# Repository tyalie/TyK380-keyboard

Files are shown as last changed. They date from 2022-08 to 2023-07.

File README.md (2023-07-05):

# TyK380 - A Logitech K380 based custom membrane keyboard

This project uses Logitech K380 keyboard and fully replaces its internal logic,
equipping it with cool features like the ZMK keyboard firmware, USB and an integrated
Li-Ion battery.

## The "_Whyyy_ thoo?"

This project was born out of the need for a very robust but lightweight keyboard and
my custom key layout needs. I wanted a keyboard where one doesn't need an extra
casing when it is squeezed between your laptop and books inside an already struggling
backpack without losing the comfort of key layers, macros, tap-dance and more.

The choice fell on the Logitech K380, as it is easy to source, cheap (for a custom
keyboard), has a build in on/off switch and already very robust. Additional perks are
the membrane switches, which I personally prefer over normal MK switches and are
essentially indestructible.

## The mod

The actual logic inside the original K380 is contained on a small PCB in the upper
left corner (from the top) with the key matrix attached using an FPC cable. This
makes it really easy to trash it and put your own PCB inside. The Li-Ion battery also
fits snugly in the previous AAA battery compartment.

The `hardware` folder contains the schematic and PCB for the mod-chip. It uses an
nRF52840 processor for wireless (and wired) connectivity, uses WS2812 for status LEDs
and integrates a sensible Li-Ion charging IC. Except for the newly added USB port and
a few more LED colors, the mod is essentially indistinguishable from the outside.

The only part of the mod, that requires a bit more effort besides potentially
soldering the PCB, is the drilling on the case for the USB-C port. In my first
revisions also integrated a completely oversized Li-Ion battery which didn't fit into
the battery bay without some subtractive manufacturing.

### Features

- nRF52840 - a low power, but feature-rich wireless IC
- ZMK support
- easy to integrate
- replaces AAA batteries with a Li-Ion battery
- a fully functioning USB port, for charging, connecting and programming
- RGB status LEDs

### Limitations

Besides not being able to really mix up the keyboard layout, the biggest problem
there is with the keyboard is the lack of phantom key blocking. The keyboard matrix
itself lacks any kind of diodes - presumably to save on costs - and is such prone to
ghosting. In normal use one doesn't really notice that, as the vendor firmware only
supports three key presses at a time and the key matrix traces are routed all over
the place, so that common key combinations won't result in ghost key presses.

## Contributing

Before you start editing the hardware here, you should install the [marbastlib
plugin](https://github.com/ebastler/marbastlib) into your KiCad. It contains the
footprints and 3D models for the HolyIoT board.

Otherwise, feel free to go. But if you want to contribute anything to the main
hardware, please open an issue first. I'm currently a bit unsure how collaboration
could work with KiCad projects as merging changes isn't really trivial here.

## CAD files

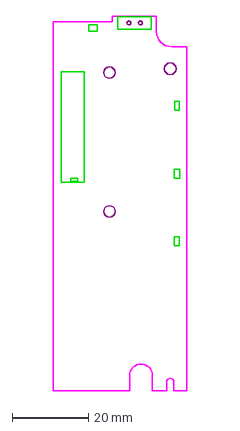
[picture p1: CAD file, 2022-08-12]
debug-tools/cad/pcb-cad.dxf
35.0 x 98.0 mm

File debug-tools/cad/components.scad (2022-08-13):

height_MDT420E02001=4.2;  // MDT420E02001
height_MDT275E02001=2.75;  // MDT245E02001
height_MDT245E02001=2.45;  // MDT245E02001
height_MDT180E02001=1.8;  // MDT180E02001

module m2_micromod(height) {
  width = 22;
  length = 5.275 + 2.275;

  union() {
    cube([length, width, height], false);
    translate([length, 0,0]) {
      cube([18, width, height + 1.4], false);
    }
  }
}

module jst_ph_2pin() {
  translate([0, -7.9, 0]) {
    cube([6, 7.9, 5.5], false);
  }
}

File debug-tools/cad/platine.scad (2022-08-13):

include <components.scad>

$fn=30;
pcb_height=1.7;
pcb_depth=36;  // min is 35

module pcb_base(thickness) {
  linear_extrude(height=thickness, center=false, convexity=10) {
    difference() {
      import (file="pcb-cad.dxf", layer="outline");
      import (file="pcb-cad.dxf", layer="details");
    }
  }
}

module pcb(thickness, full_depth) {
  scale([1,-1,-1]) {
    union() {
      pcb_base(thickness);

      translate([35,0,0]) {
        cube([full_depth - 35, 90, thickness], center=false);
      }

    }
  }
}

module populated_pcb(thickness, depth) {
  pcb(thickness, depth);

  // pcb components
  translate([7.5, -22, 0]) {
    rotate([0,0,-90]) {
      m2_micromod(height_MDT275E02001);
    }
  }

  translate([0,-9,0]) {
    jst_ph_2pin();
  }
}

populated_pcb(pcb_height, pcb_depth);

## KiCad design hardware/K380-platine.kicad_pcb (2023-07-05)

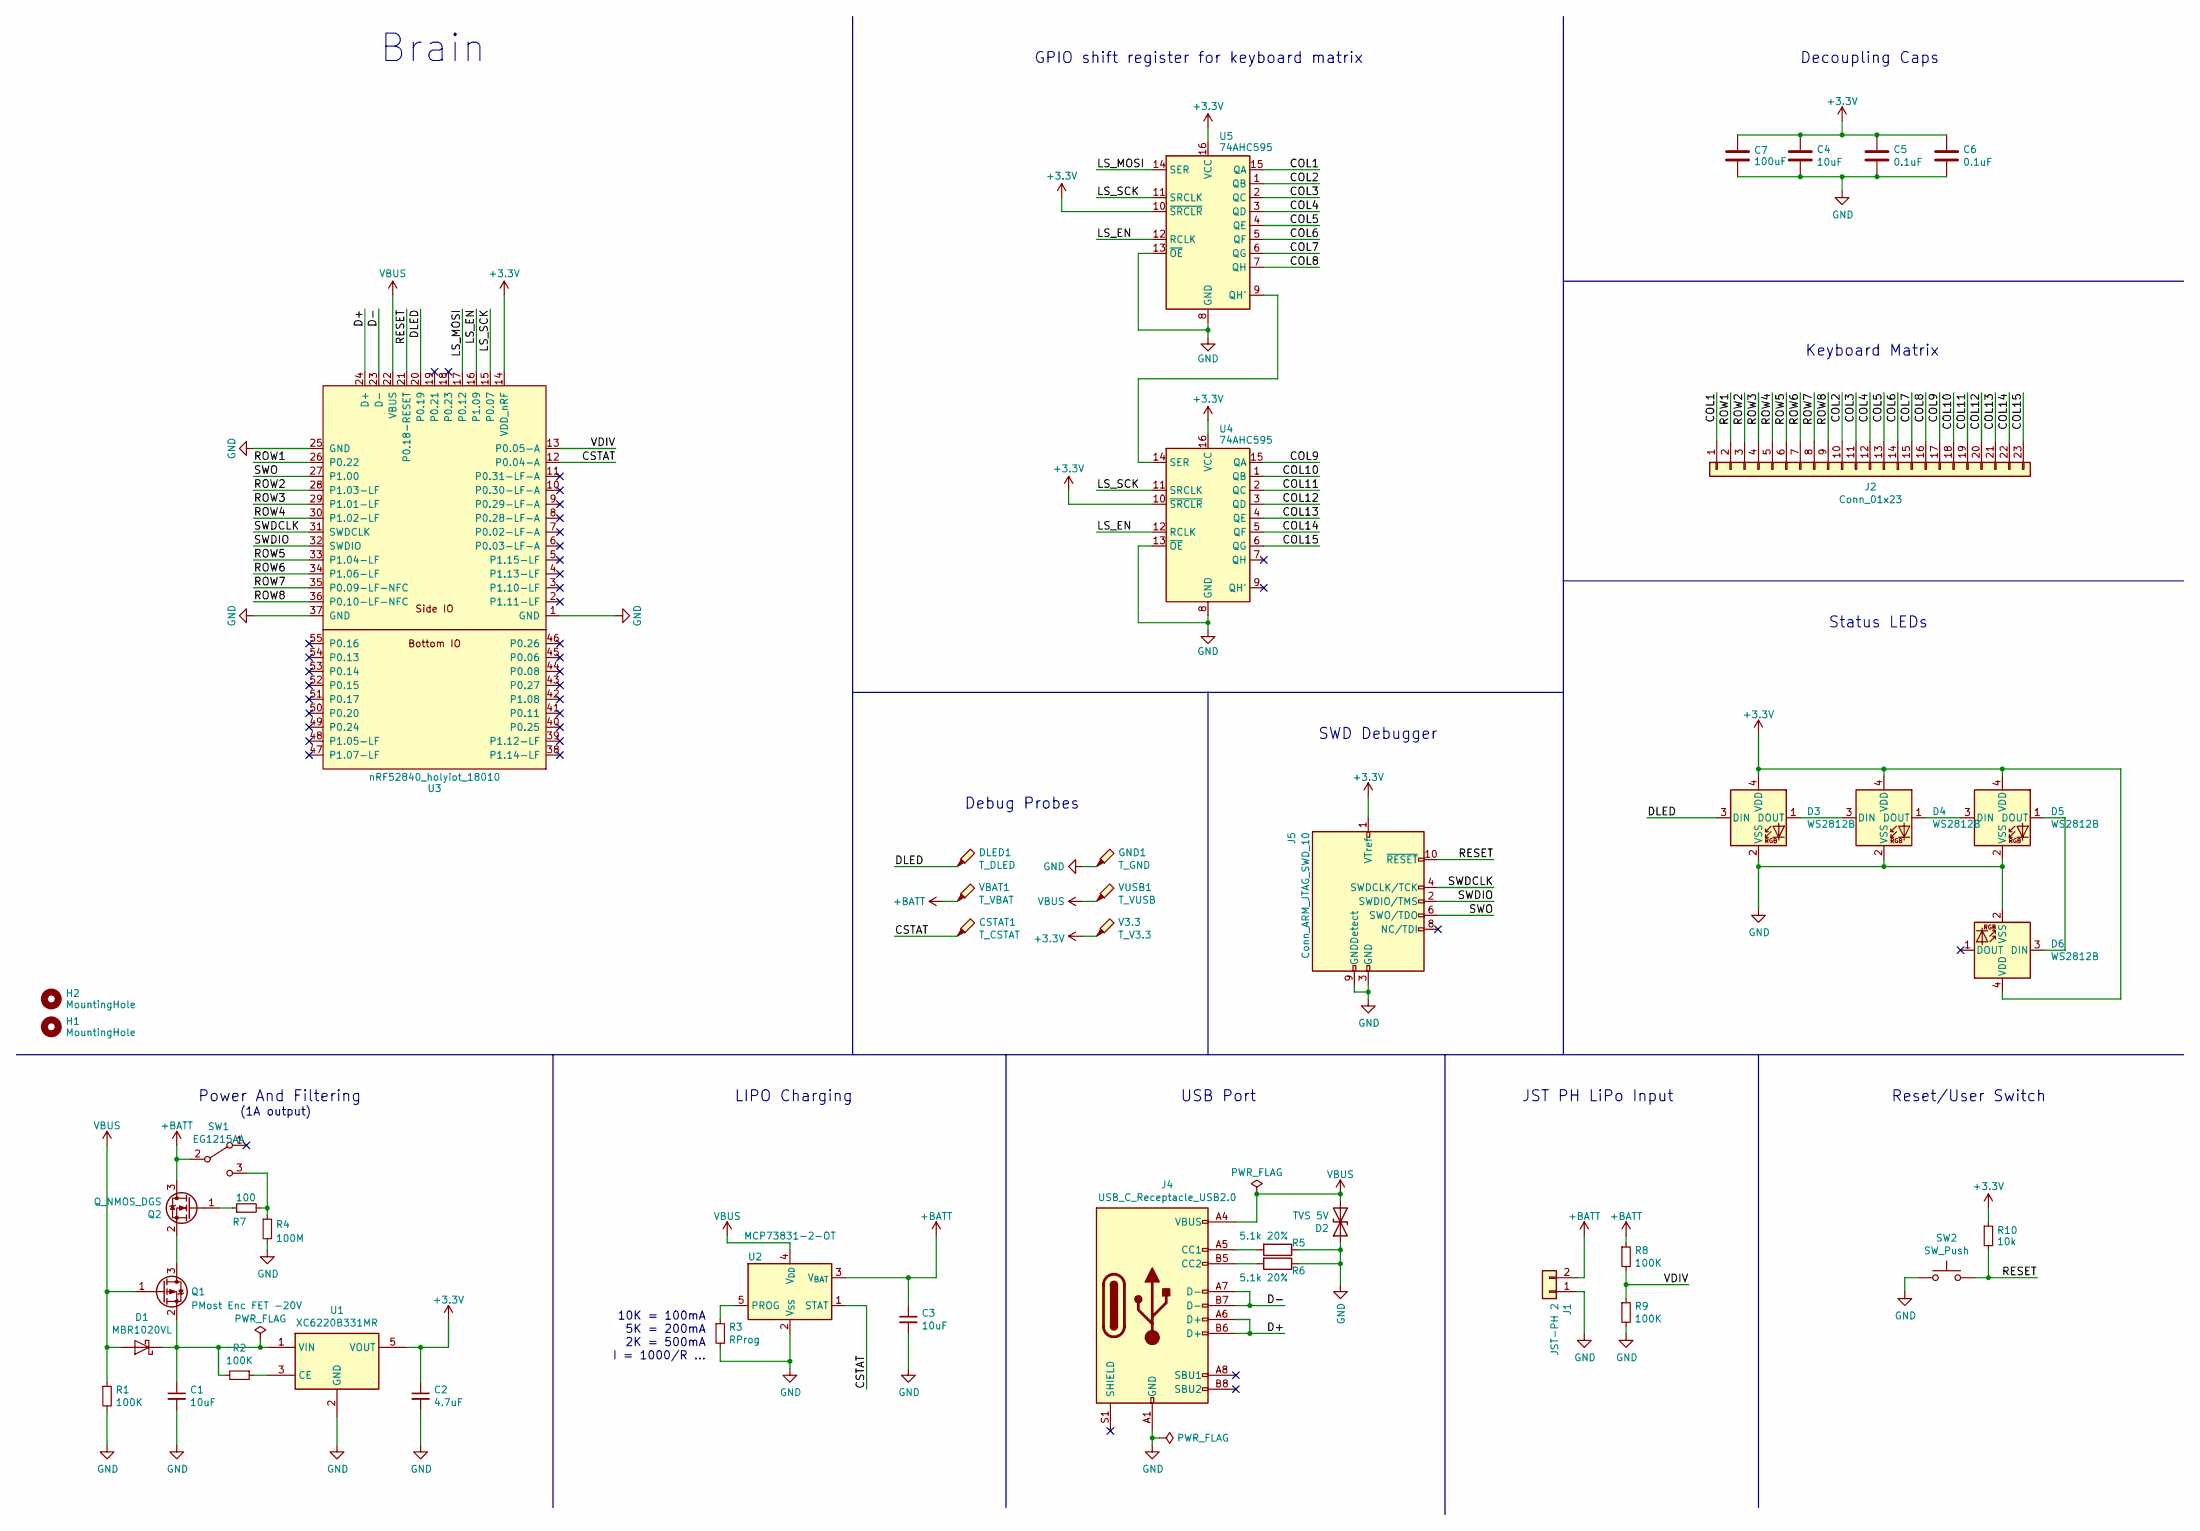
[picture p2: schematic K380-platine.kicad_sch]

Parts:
C1, C3, C4: 10uF; C_0603_1608Metric_Pad1.08x0.95mm_HandSolder
C2: 4.7uF; C_0603_1608Metric_Pad1.08x0.95mm_HandSolder
C5, C6: 0.1uF; C_0603_1608Metric_Pad1.08x0.95mm_HandSolder
C7: 100uF; C_0603_1608Metric_Pad1.08x0.95mm_HandSolder
CSTAT1: T_CSTAT; TestPoint_Pad_D1.0mm
D1: MBR1020VL; D_SOD-123F
D2: TVS 5V; D_SMA_Handsoldering
D3, D4, D5, D6: WS2812B; WS28122020
DLED1: T_DLED; TestPoint_Pad_D1.0mm
GND1: T_GND; TestPoint_Pad_D1.0mm
H1, H2: MountingHole; MountingHole_3.2mm_M3_DIN965_Pad
J1: JST-PH 2; JST_PH_S2B-PH-SM4-TB_1x02-1MP_P2.00mm_Horizontal
J2: Conn_01x23; TE_2-84952-3_1x23-1MP_P1.0mm_Horizontal
J4: USB_C_Receptacle_USB2.0; USB_C_Receptacle_GCT_USB4085
J5: Conn_ARM_JTAG_SWD_10; PinHeader_2x05_P1.27mm_Vertical_SMD
Q1: PMost Enc FET -20V; SOT-23
Q2: Q_NMOS_DGS; SOT-23
R1, R2, R8, R9: 100K; R_0603_1608Metric_Pad0.98x0.95mm_HandSolder
R3: RProg; R_0603_1608Metric_Pad0.98x0.95mm_HandSolder
R4: 100M; R_0603_1608Metric_Pad0.98x0.95mm_HandSolder
R5, R6: 5.1k 20%; R_0603_1608Metric_Pad0.98x0.95mm_HandSolder
R7: 100; R_0603_1608Metric_Pad0.98x0.95mm_HandSolder
R10: 10k; C_0603_1608Metric_Pad1.08x0.95mm_HandSolder
SW1: EG1215AA
SW2: SW_Push; MJTP1140AAUTR - Fixed
U1: XC6220B331MR; SOT-23-5
U2: MCP73831-2-OT; SOT-23-5
U3: nRF52840_holyiot_18010; nRF52840_holyiot_18010_HS_simple
U4, U5: 74AHC595; TSSOP-16_4.4x5mm_P0.65mm
V3.3: T_V3.3; TestPoint_Pad_D1.0mm
VBAT1: T_VBAT; TestPoint_Pad_D1.0mm
VUSB1: T_VUSB; TestPoint_Pad_D1.0mm

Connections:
+3.3V: C2.1, C4.1, C5.1, C6.1, C7.1, D3.4 (VDD), D4.4 (VDD), D5.4 (VDD), D6.4 (VDD), J5.1 (VTref), R10.1, U1.5 (VOUT), U3.14 (VDD_nRF), U4.10 (~SRCLR), U4.16 (VCC), U5.10 (~SRCLR), U5.16 (VCC), V3.3.1
+BATT: C3.1, J1.2, Q2.3 (D), R8.1, SW1.2 (B), U2.3 (V_{BAT}), VBAT1.1
/COL1: J2.1, U5.15 (QA)
/COL2: J2.10, U5.1 (QB)
/COL3: J2.11, U5.2 (QC)
/COL4: J2.12, U5.3 (QD)
/COL5: J2.13, U5.4 (QE)
/COL6: J2.14, U5.5 (QF)
/COL7: J2.15, U5.6 (QG)
/COL8: J2.16, U5.7 (QH)
/COL9: J2.17, U4.15 (QA)
/COL10: J2.18, U4.1 (QB)
/COL11: J2.19, U4.2 (QC)
/COL12: J2.20, U4.3 (QD)
/COL13: J2.21, U4.4 (QE)
/COL14: J2.22, U4.5 (QF)
/COL15: J2.23, U4.6 (QG)
/CSTAT: CSTAT1.1, U2.1 (STAT), U3.12 (P0.04-A)
/D+: J4.A6 (D+), J4.B6 (D+), U3.24 (D+)
/D-: J4.A7 (D-), J4.B7 (D-), U3.23 (D-)
/DLED: D3.3 (DIN), DLED1.1, U3.20 (P0.19)
/LS_EN: U3.16 (P1.09), U4.12 (RCLK), U5.12 (RCLK)
/LS_MOSI: U3.17 (P0.12), U5.14 (SER)
/LS_SCK: U3.15 (P0.07), U4.11 (SRCLK), U5.11 (SRCLK)
/RESET: J5.10 (~RESET), R10.2, SW2.2, U3.21 (P0.18-RESET)
/ROW1: J2.2, U3.26 (P0.22)
/ROW2: J2.3, U3.28 (P1.03-LF)
/ROW3: J2.4, U3.29 (P1.01-LF)
/ROW4: J2.5, U3.30 (P1.02-LF)
/ROW5: J2.6, U3.33 (P1.04-LF)
/ROW6: J2.7, U3.34 (P1.06-LF)
/ROW7: J2.8, U3.35 (P0.09-LF-NFC)
/ROW8: J2.9, U3.36 (P0.10-LF-NFC)
/SWDCLK: J5.4 (SWDCLK/TCK), U3.31 (SWDCLK)
/SWDIO: J5.2 (SWDIO/TMS), U3.32 (SWDIO)
/SWO: J5.6 (SWO/TDO), U3.27 (P1.00)
/VDIV: R8.2, R9.1, U3.13 (P0.05-A)
GND: C1.2, C2.2, C3.2, C4.2, C5.2, C6.2, C7.2, D2.1 (A1), D3.2 (VSS), D4.2 (VSS), D5.2 (VSS), D6.2 (VSS), GND1.1, J1.1, J4.A1 (GND), J4.A12 (GND), J4.B1 (GND), J4.B12 (GND), J5.3 (GND), J5.5 (GND), J5.9 (GNDDetect), R1.2, R3.2, R4.2, R5.1, R6.1, R9.2, SW2.1, U1.2 (GND), U2.2 (V_{SS}), U3.1 (GND), U3.25 (GND), U3.37 (GND), U4.8 (GND), U4.13 (~OE), U5.8 (GND), U5.13 (~OE)
unnamed: C1.1, D1.1 (K), Q1.2 (S), R2.2, U1.1 (VIN)
unnamed: D3.1 (DOUT), D4.3 (DIN)
unnamed: D4.1 (DOUT), D5.3 (DIN)
unnamed: D5.1 (DOUT), D6.3 (DIN)
unnamed: J4.A5 (CC1), R5.2
unnamed: J4.B5 (CC2), R6.2
unnamed: Q1.3 (D), Q2.2 (S)
unnamed: Q2.1 (G), R7.1
unnamed: R4.1, R7.2, SW1.3 (C)
unnamed: R2.1, U1.3 (CE)
unnamed: R3.1, U2.5 (PROG)
unnamed: U4.14 (SER), U5.9 (QH')
VBUS: D1.2 (A), D2.2 (A2), J4.A4 (VBUS), J4.A9 (VBUS), J4.B4 (VBUS), J4.B9 (VBUS), Q1.1 (G), R1.1, U2.4 (V_{DD}), U3.22 (VBUS), VUSB1.1

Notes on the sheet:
JST PH LiPo Input
USB Port
Brain
SWD Debugger
GPIO shift register for keyboard matrix
Reset/User Switch
Debug Probes
Power And Filtering
Status LEDs
Keyboard Matrix
10K = 100mA 5K = 200mA 2K = 500mA I = 1000/R ...
(1A output)
Decoupling Caps
LIPO Charging

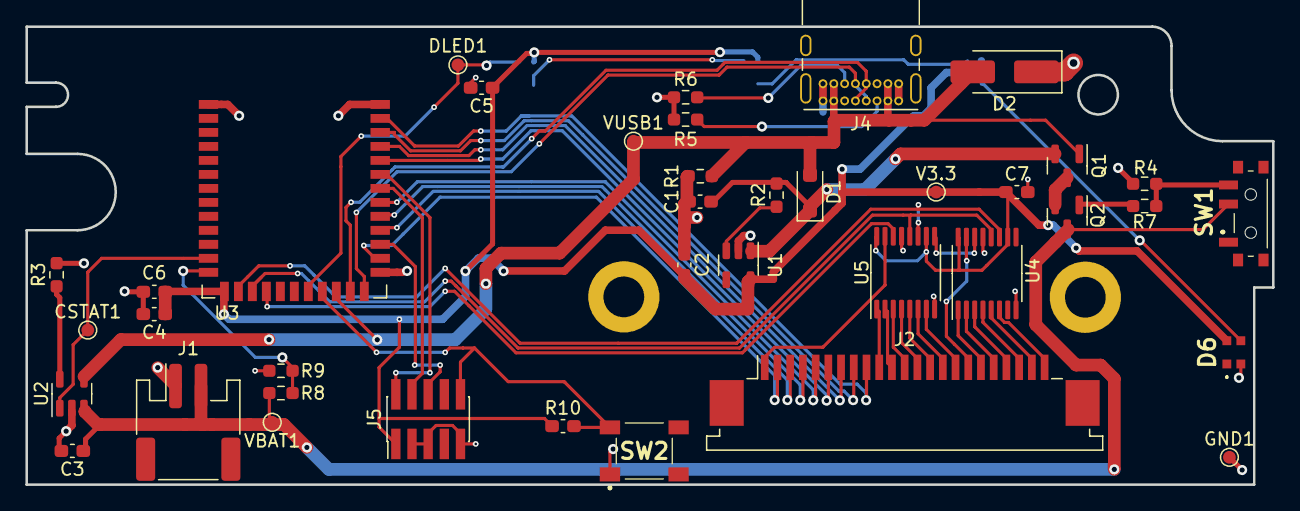
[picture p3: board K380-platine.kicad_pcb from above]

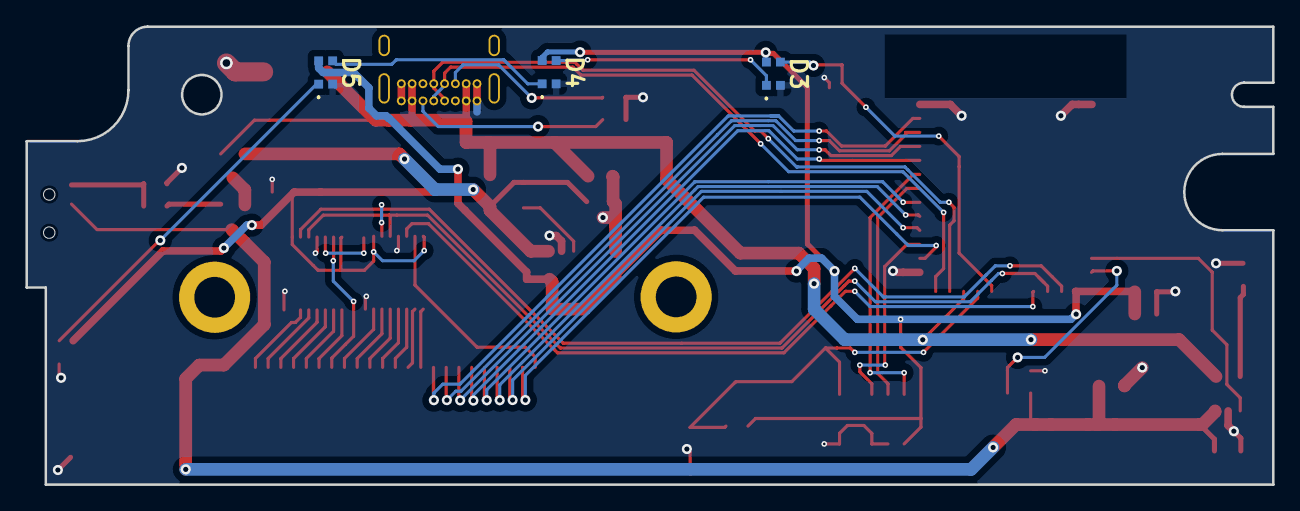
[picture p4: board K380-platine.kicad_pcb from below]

Board: 2 copper layers, 98.0 x 36.0 mm, 44 parts (3 on the bottom side), 51 nets.

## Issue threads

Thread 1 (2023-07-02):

roadmap to a v0.2 revision

tyalie, 2023-07-02:
Issues and improvements that I've discovered with the v0.1

### Problems
- [x] battery MOSFET is __still__ wired incorrectly
    - [x] on/off switch has a third pin -> no inversion needed
- [ ] change footprint for WS2812 LEDs (actually use the correct one)
- [ ] try out a thinner PCB (Aislers 1.6mm is too thick)

### Improvements
- [ ] move away from sparkfun module to nRF52840 directly on PCB
- [ ] change global lables to net labels for KiCad convention compliance
- [ ] (optional) add Cortex-M trace interface :D

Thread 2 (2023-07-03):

move away from sparkfun module to nRF52840 directly on PCB

tyalie, 2023-07-03:
This is a bit of a bigger overhaul, as it will mean that all the nRF52840 logic that is currently so neatly contained on the SparkFun module (e.g. antenna, clocks, flash) needs to be put directly on the PCB.

The very big advantage of this is, that we remove the SparkFun module and the M.2 connector. Both are very hard to source depending where you're from. Additionally the M.2 connector only works here because it has exactly the right height, which makes us prone to supply chain or deprecation issues.

#### Tasks
- [x] prepare change by moving SparkFun module onto its own sheet
- [x] adapt public schematics for nRF module to our purposes
  - will require a bit of research but look for example to
    - https://gitlab.aachen.ccc.de/cpresser/catears
    - nRFMicro
- [ ] verify

tyalie, 2023-07-03:
Okay so. I've managed to do most of the schematic. Only piece missing is the RF antenna.

tyalie, 2023-07-05:
Okay. So I've aborted the idea of putting the nRF52 directly onto the board. The main problem is twofold:
1. it's really hard to get RF and MCU stuff right - especially the first time
2. it's essentially not possible to put traces everywhere without paying a pretty penny to the PCB manufacturer. The spacing between the pads on the nRF52840 package is far to small to really use all pins. For JLCPCB the extra cost would have been about 300% per PCB...

I've now decided on the HolyIoT board, which is available relatively cheaply, but is still very easy too use. Additionally I've moved to a gpio shift-register concept.

Closed 2023-07-05.

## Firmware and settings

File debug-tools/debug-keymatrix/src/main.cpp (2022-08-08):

#include <Arduino.h>
#include <HardwareSerial.h>
#include <string.h>
#include <stdarg.h>

#define PRINT_FULL_MATRIX 1

#define PN (uint8_t)-1
#define COLS_SIZE 15
#define ROWS_SIZE 8

const static uint8_t PIN_COLS[] = {
  27,  8, 11, 15, 40, 37, 39,  6,  
   4,  5, 29,  3, 45, 44, 43
};

const static uint8_t PIN_ROWS[] = {
  31,  2, 10,  9, 46, 36, 38, 17
};


bool read_pins(uint8_t arr[ROWS_SIZE][COLS_SIZE]);
void print_matrix(uint8_t arr[ROWS_SIZE][COLS_SIZE]);
void print_matrix_short(uint8_t arr[ROWS_SIZE][COLS_SIZE]);
uint64_t calculate_hash(uint8_t *arr, size_t length);
void mprintf(char* format, ...);
void mflush();

void setup() {
  Serial.begin(9600);
  while (!Serial) { ; }
  Serial.println("Start");

  for (const uint8_t &i : PIN_COLS) {
    pinMode(i, INPUT);
  }
  for (const uint8_t &i : PIN_ROWS) {
    pinMode(i, INPUT);
  }
 
  Serial.println("- Pins initialized");
  Serial.println("- Setup complete");
}


uint64_t previous_hash = 0;

void loop() {
  uint8_t matrix[ROWS_SIZE][COLS_SIZE] = {0};
  read_pins(matrix);

  uint64_t hash = calculate_hash(*matrix, sizeof(matrix));
  if (previous_hash != hash) {

    if (previous_hash == 0 || PRINT_FULL_MATRIX) {
      // print matrix once
      // Serial.print("\033[2J");
      print_matrix_short(matrix);
      print_matrix(matrix);
    } else {
      print_matrix_short(matrix);
    }
  }
  previous_hash = hash;

  delay(10);
}


bool read_pins(uint8_t arr[ROWS_SIZE][COLS_SIZE]) {
  memset(arr, 0xFF, ROWS_SIZE * COLS_SIZE * sizeof(bool));

  for (size_t i = 0; i < ROWS_SIZE; i++) {
    uint8_t main = PIN_ROWS[i];
    if (main == PN)
      continue;

    pinMode(main, OUTPUT);
    digitalWrite(main, LOW);
    delay(1);

    for (size_t k = 0; k < COLS_SIZE; k++) {
      uint8_t listener = PIN_COLS[k];
      if (listener == main || listener == PN)
        continue;

      pinMode(listener, INPUT_PULLUP);
      arr[i][k] = 0;
      for (size_t s = 0; s < 3; s++) {
        arr[i][k] += digitalRead(listener);
      }
      arr[i][k] = arr[i][k] >= 2;
      
      pinMode(listener, INPUT);
    }

    pinMode(main, INPUT);
  }

  return true;
}

void print_matrix(uint8_t arr[ROWS_SIZE][COLS_SIZE]) {
  mprintf("    ");
  for (size_t j = 0; j < COLS_SIZE; j++)
    mprintf("%#2u ", j);
  mprintf("\n");

  for (size_t i = 0; i < ROWS_SIZE; i++) {
    mprintf("%#2u: ", i);
    for (size_t j = 0; j < COLS_SIZE; j++) {
      char c = '?';
      if (arr[i][j] == HIGH)
        c = ' ';
      else if (arr[i][j] == LOW)
        c = '#';

      mprintf(" %c ", c);
    }
    mprintf("\n");
  }

  mflush();
}

void print_matrix_short(uint8_t arr[ROWS_SIZE][COLS_SIZE]) {
  mprintf("\n-------------\n");
  for (size_t i = 0; i < ROWS_SIZE; i++) {
    for (size_t j = 0; j < COLS_SIZE; j++) {
      if (arr[i][j] == LOW) {
        mprintf("Hit: %2u / %2u\n", i, j);
      }
    }
  }
  mflush();
}


char buff[200];
char *target = NULL;

void mprintf(char* format, ...) {
  va_list argp;
  va_start(argp, format);

  if (target == NULL)
    target = buff;

  target += vsprintf(target, format, argp);

  char* p = strchr(buff, '\n');
  if (p != NULL) {
    *p = '\0';
    Serial.println(buff);
    memmove(buff, p, (p - buff));
    target = buff;
  }
}

void mflush() {
  Serial.print(buff);
  buff[0] = '\0';
  target = buff;
}

/**
 * @brief Calculating sdbm hash for input byte string
 * 
 * @param arr The bytes
 * @param length length of input array
 * @return uint64_t The hash
 */
uint64_t calculate_hash(uint8_t *arr, size_t length) {
  uint64_t hash = 0;
  for (size_t i = 0; i < length; i++) {
    hash = arr[i] + (hash << 6) + (hash << 16) - hash;
  }
  return hash;
}

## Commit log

2022-05-26 Basic PCB outline of K380 keyboard
    [K380-platine.kicad_pcb, K380-platine.sch]
2022-05-26 Add few major components
    - completely unconnected
    - created schematic for M.2 sparkfun nRF52840 module
    - included SparkFun footprint library
    - position a few major components on the footprint
    [K380-platine.kicad_pcb, K380-platine.sch]
2022-05-27 Schem: Add Power and Charging Circuit
    [K380-platine.sch]
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2022-05-29 Add battery con and user switches
    - changed schematic page design
    - battery can be disabled via slider switch
    - integrated library loader
    - add user and reset switch
    [K380-platine.sch]
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2022-05-29 Finish schematics
    - decoupling capacitors
    - connected keyboard matrix
    - changed from user to boot pin
    - add SWD connector
    - connect MicroMod connector
    [K380-platine.sch]
2022-05-29 Assigned footprint to all components
    [K380-platine.sch]
2022-05-29 Fix footprint of USB-c connector
    [K380-platine.sch]
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2022-05-29 Reordered keyboard matrix pins
    - layout traces isn't as random as before
    [K380-platine.kicad_pcb, K380-platine.sch]
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2022-05-29 Change pin of DLED and CSTAT
    - cstat was misspelled so KiCad made no connection
    - DLED is closer to where it needs to be
    [K380-platine.kicad_pcb, K380-platine.sch]
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2022-05-29 Finished routing
    - GND is zone fill in bottom
    [K380-platine.kicad_pcb, K380-platine.sch]
2022-05-30 Simplified tracks
    as GND got to be the bottom layer, a few tracks were able be routed
    differently, simplifying the layout and increasing the connection
    between larger sections of GND.
    Also on a few components connection to GND was given the same track
    width as the power delivering lines connected to them.
    [K380-platine.kicad_pcb]
2022-05-30 Add drill mills
    - needed to reroute a few tracks for it to fit
    [K380-platine.kicad_pcb]
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2022-05-30 Removed unnecessary text on silk screen
    Drill holes had Ref** on PCB
    [K380-platine.kicad_pcb]
2022-05-30 Moved a few silk screen text that were unreadable
    [K380-platine.kicad_pcb]
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2022-08-09 Moved pcb 2D cad design file into folder
    [pcb-cad.dxf, platine.scad]
2022-08-09 Changed depth to 36mm
    The 38mm PCB fits snuggly into the top part of the case, but doesn't
    allow the bottom shell to close correctly.
    [platine.scad]
2022-08-12 3D: Flattened M.2 header
    Previous M.2 header was 4.2mm high and didn't fit into the case. Now
    switched to a 1.8mm high version and it fit's quite snuggly
    [components.scad, platine.scad]
2022-08-12 PCB: Updated from KiCad 5.99 to KiCad 6 file format
    [K380-platine.kicad_pcb]
2022-08-12 PCB: Resized PCB to fit new size constraints
    Testing with mockups showed that a 38mm deep PCB is to large to fit into
    the K380 case. A feasible size is 36mm instead. This required the
    movement of a few components on the northern most edge, which was done
    in this commit.
    Other constraints like height aren't included yet. (see C4, C6)
    [K380-platine.kicad_pcb]
2022-08-12 PCB - fix: One GND of USB wasn't connected to PCB
    [K380-platine.kicad_pcb]
2022-08-12 PCB: Fix DRC warnings for PCB
    - excluded fix for C4 and C6 from this commit
    [K380-platine.kicad_pcb]
2022-08-12 PCB: Fix boot / reset button footprint
    The MJTP1140AAUTR is internally differently wired than the original
    footprint pad numbers would suggest. This lead to a faulty PCB which
    needed a bit of rewiring and trace cutting effort.
    [K380-platine.kicad_pcb]
2022-08-12 PCB: Moved caps out from under the M.2 module
    Due to chosing a M.2 header with a height of 1.8mm instead of 4.2mm, the
    space under the SparkFun module decreased significantly. This left no
    space for any components under the module, so they needed to be moved.
    This affected the 3.3V buffering caps C4 and C6.
    [K380-platine.kicad_pcb]
2022-08-12 PCB: Fixed wrongly wired NMOS
    I've ordered a GSD mosfet, which didn't go well with the previous
    pin layout so needed to change that for further layouts.
    Also assigned previously selected footprints to the symbols in the
    schematics accordingly (e.g. smaller resistors, …)
    [K380-platine.kicad_pcb, K380-platine.kicad_sch]
2022-08-12 PCB: Migrated from KiCad 5 to KiCad 6 files
    deleted old and unneeded file formats and replaced them
    with their newer counterparts.
    - removed .pro and .sch files as they migrated to `.kicad_*`
    - migrated library symbols from `-cache.lib`
    - updated sch path references of `.kicad_pcb`
    [K380-platine.kicad_pcb, K380-platine.sch]
2022-08-12 PCB: changed via sizes
    Changed all vias to 0.8mm plated, with 0.4mm drill parameter
    Noticed that previously used via sizes are quite over dimensioned for
    the purpose they need to serve. Calculated required via sizes using
    NinjaCalc and adapted PCB accordingly.
    [K380-platine.kicad_pcb]
2022-08-12 CAD: modified upper right hole size to r=1.55mm
    The pin on the case is almost exactly 3mm thick, resulting in a very
    tight fit in the resulting PCB, 3D print, … This hole though doesn't
    need to be so tight fitting, that is why I increased the radius
    [K380-platine.kicad_pcb, pcb-cad.dxf]
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2022-08-13 Changed height of M.2 to 2.45mm
    The 1.8mm heigh M.2 E header would put the module flat on the PCB and
    has a different footprint than headers that are higher. The former isn't
    feasible as the SparkFun module has a flash storage on the bottom.
    Additionally the different footprint isn't publicly available right now
    and would need to be modeled on my own.
    [components.scad, platine.scad]
2022-08-13 Changed M.2 header height to 2.75mm
    the 2.45mm doesn't really exist on the market
    [components.scad, platine.scad]
2023-06-23 not sure what changed
    something something the M.2 connector
    [K380-platine.kicad_sch]
2023-07-02 keyboard: power: Fixed on/off switch behavior
    changes:
    - fix on/off switch behavior
    - move away from global labels for power symbols
    - add SWO trace to Cortex-M debug connector
    The on/off switch is a SPDT switch which has two possible
    configurations. Use the one where I don't need to invert the signal as
    before.
    Also fixed up the employed nMOSFET, as it was incorrectly (Drain and
    Source was flipped). Also added pull-down resistor to gate.
    [K380-platine.kicad_pcb, K380-platine.kicad_sch]
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2023-07-02 reorder: moved old stuff into folder debug-tools
    Things like the 3D model and my debug-keymatrix minimal project, which
    helped me figure out the dimensions and the internal wiring, are not
    needed anymore. In turn they have now been moved into a folder called
    `debug-tools`.
    [components.scad, pcb-cad.dxf, platine.scad]
2023-07-02 refactor: rename schematics folder into hardware
    Had previously the non-descriptive name "K380-platine" for the folder
    which contained all schematics. It's now named into "hardware" (for now)
    [K380-platine.kicad_pcb, K380-platine.kicad_sch]
2023-07-02 firmware: Set submodule to track correct branch
2023-07-03 hardware: update KiCad and fix library issue
    - opened all files in newest KiCad version (7.0.5) and let it update
    - fixed library Symbol for EG1215AA switch
    - design of through holes threw "Invalid zero sized pads" error
    - fixed according to this post:
    - https://forum.kicad.info/t/invalid-zero-sized-pad-pinned-to-1-m-in-file-error-in-footprint-file/40908/4
    [K380-platine.kicad_pcb, K380-platine.kicad_sch]
2023-07-03 hardware: update WS2812B 2020 symbol [unrooted]
    Previously the footprint and symbol pinout didn't match the WS2812B 2020
    datasheet. I previously thought that I could get away with just using
    the WS2812B symbol, but in my blissful ignorance I didn't notice that
    the WS2812B symbol has a different ordering of the number pins.
    This patch introduces a new WS2812B_2020 symbol in LibraryLoader, which
    is a copy of the WS2812B symbol, but with the pinout from the datasheet.
    [K380-platine.kicad_sch]
2023-07-03 hardware: schematic: Moved MCU to separate page
    With this separation of content, it will make the future change of
    directly placing the nRF52840 module onto the board much easier, as all
    parts that replace the micromod module will be part of this new sheet.
    [K380-platine.kicad_pcb, K380-platine.kicad_sch, subsystem-cpu.kicad_sch]
2023-07-05 hardware: first nRF52840 raw tries
    The current schematic should (in theory) be a complete setup for the
    nRF52840 chip with power and everything.
    In the footprint first routing attempts have been made, but this has
    been without real success for now, especially as the nRF52840 is a hell
    of a chip to implement. Ignoring the whole "need to do own RF" here,
    it's almost impossible to get the inner pins out from under the chip
    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
    [K380-platine.kicad_pcb, K380-platine.kicad_sch, subsystem-cpu.kicad_sch]
2023-07-05 Revert "hardware: first nRF52840 raw tries"
    Wanna start from a clean slate. See referenced commit on why I'm doing
    this.
    This reverts commit 5420c1d1e1bdfd9146d776c48bdd16e2d166426d.
    [K380-platine.kicad_pcb, K380-platine.kicad_sch, subsystem-cpu.kicad_sch]
2023-07-05 hardware: completed rev 0.2α (pre-verify)
    This is a bigger change from the iteration. The MicroMod has been
    replaced with an HolyIoT nRF52840, which can be directly soldered onto
    the board. This guarantees minimal space usage, while reducing the
    complexity to implement an MCU on our own.
    Additionally this iteration moves away from reserving a gpio port per
    keyboard matrix trace, and instead makes use of an GPIO shift register
    (74AHC595A). They are quite popular and also have support in ZMK since a
    few weeks ago.
    This commit adheres to the design rules for a 2 layer PCB and passes all
    DRC checks.
    [K380-platine.kicad_pcb, K380-platine.kicad_sch, subsystem-cpu.kicad_sch]
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
